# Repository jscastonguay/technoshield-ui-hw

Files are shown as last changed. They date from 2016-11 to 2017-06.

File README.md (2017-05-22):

# Technoshield User Interface HW

See the folling link for further details: [Technoshield Hackaday project](https://hackaday.io/project/21892-technoshield-user-interface)

## Release note

This is the description of the Technoshield HW revisions.

### Revision A

2017-05-03

The issue #1 has been fixed. This is the first revision that should be produced for students.

### Revision --
The first protoype revision.

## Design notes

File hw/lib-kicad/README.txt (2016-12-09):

Here are the sources of the labraries:

* KiCad-Libraries:
  https://github.com/imciner2/KiCad-Libraries
  Connectors.pretty rename Connectors_lib.pretty to be able to add it in 
  kicad. The Connectors.pretty already exist in kicad libraries.
  
* technoshield-lb:
  Libraries done during this project development.

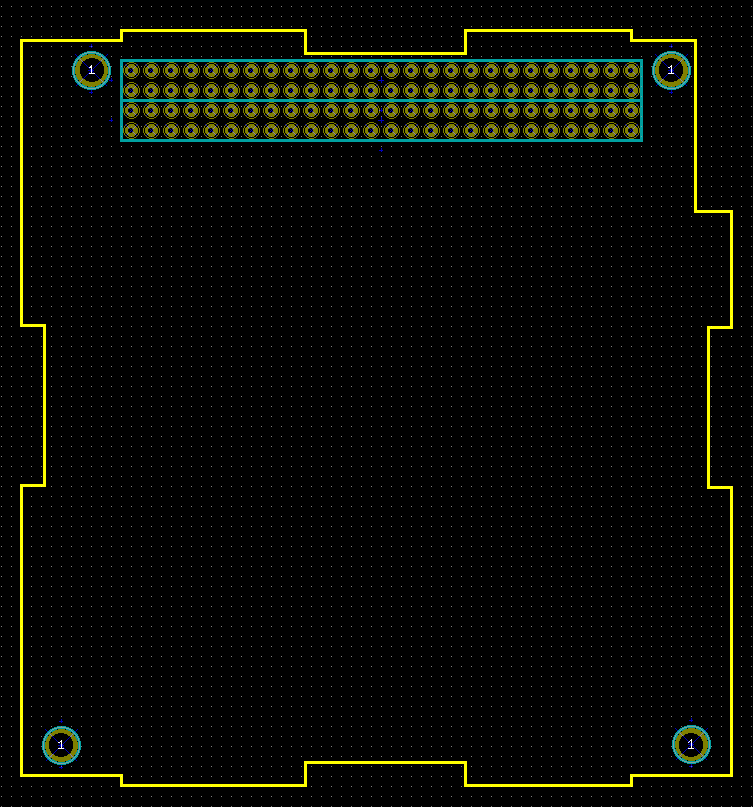
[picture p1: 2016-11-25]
hw/lib-kicad/KiCad-Libraries/Templates/CubeSatKit_StackBoard/meta/Board.png

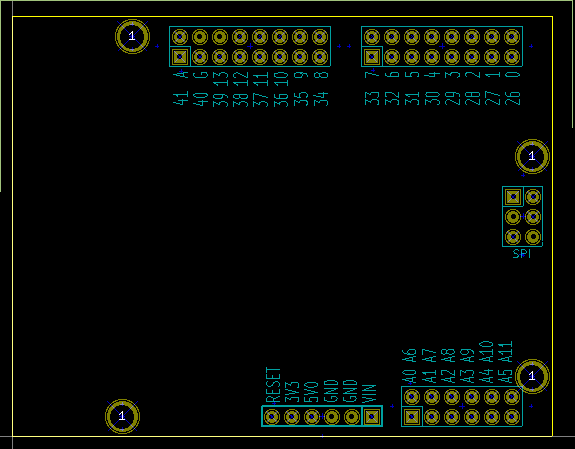
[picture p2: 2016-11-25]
hw/lib-kicad/KiCad-Libraries/Templates/Chipkit_Shield_uC/meta/board.png

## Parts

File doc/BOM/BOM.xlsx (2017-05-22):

Part list Technoshield User interface
Stock | QTE | Ref | Description | P/N | Fournisseur
 | 5 | R1, R2, R3, R4, R7 | RES 10K OHM 1/8W 5% CF AXIAL | CF18JT10K0CT-ND | DigiKey
 | 1 | R16 | RES 750 OHM 1/8W 5% CF AXIAL | CF18JT750RCT-ND | DigiKey
 | 3 | R11, R12, R13 | RES 1.6K OHM 1/8W 5% CF AXIAL | CF18JT1K60CT-ND | DigiKey
 | 2 | R14, R15 | RES 4.7K OHM 1/8W 5% CF AXIAL | CF18JT4K70CT-ND | DigiKey
 | 1 | RV1 | TRIMMER 10K OHM 0.2W PC PIN | 3319P-103-ND | DigiKey
 | 6 | C1, C2, C3, C4, C5, C6 | CAP CER 0.1UF 50V X7R RADIAL | 490-8815-ND | DigiKey
 | 1 | D1 | LED RED CLEAR 2PLCC SMD | 475-1180-1-ND | DigiKey
 | 1 | D2 | LED YELLOW CLEAR 2PLCC SMD | 475-2798-1-ND | DigiKey
 | 2 | D3, D4 | LED GREEN CLEAR 2PLCC SMD | 475-2752-1-ND | DigiKey
 | 1 | Q1 | TRANS NPN 40V 0.6A SMD SOT23-3 | MMBT2222A-FDICT-ND | DigiKey
 | 1 | U1 | DC/DC CONVERTER +/-15V 1W | 102-2721-ND | DigiKey
 | 2 | U2, U3 | IC I/O EXPANDER I2C 8B 18DIP | MCP23008-E/P-ND | DigiKey
 | 1 | U4 | IC BUFFER HEX NON-INV 16SOIC | 1727-6410-1-ND | DigiKey
 | 1 | J1 | CONN MICRO SD CARD HINGED TYPE | 101-00303-68-1-ND | DigiKey | Non-stock discontinued
 | 6 | JP1, JP2, JP3, JP4, JP5, JP6 | SIL VERTICAL PC TAIL PIN HEADER | 952-2262-ND | DigiKey
 | 6 | -- | *Jumper for JP1-JP2-JP3-JP4-JP5-JP6 SHUNT JUMPER .1" BLACK GOLD | 3M9580-ND | DigiKey
 | 1 | P1 | CONN HEADER FEMALE 3POS .1" GOLD | S7036-ND | DigiKey
 | 6 | SW1, SW2, SW3, SW4, SW5, SW6 | SWITCH TACTILE SPST-NO 0.05A 24V | 450-2055-1-ND | DigiKey
 | 1 | P3 | 6 pin 2,54p stack 11mm long tall leg female header | --- | AliExpress
 | 2 | P2, P5 | 8 pin 2.54p Stack 11mm long Tall Leg Female header | --- | AliExpress
 | 1 | P4 | 10 pin 2.54 Stack 11mm Long Tall Leg Female Header | --- | AliExpress

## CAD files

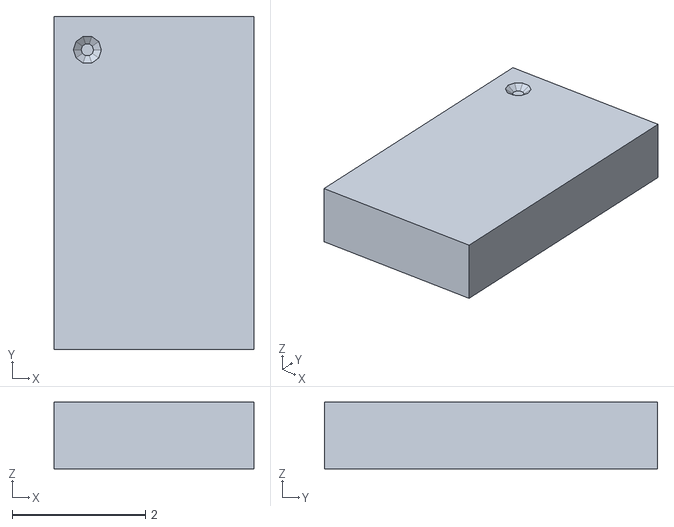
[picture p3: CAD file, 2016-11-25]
hw/lib-kicad/KiCad-Libraries/3D/SourceFiles/ADXL345/ADXL345-Wings.stl
3.00 x 5.00 x 1.00

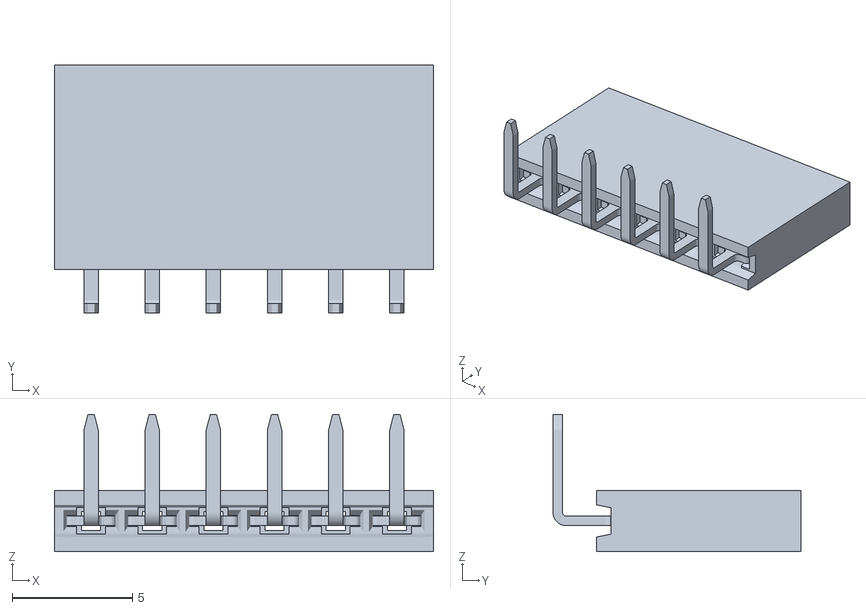
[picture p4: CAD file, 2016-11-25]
hw/lib-kicad/KiCad-Libraries/3D/SourceFiles/Connectors/CONN_1x6/CONN_1x6_Female.stl
15.7 x 10.3 x 5.69

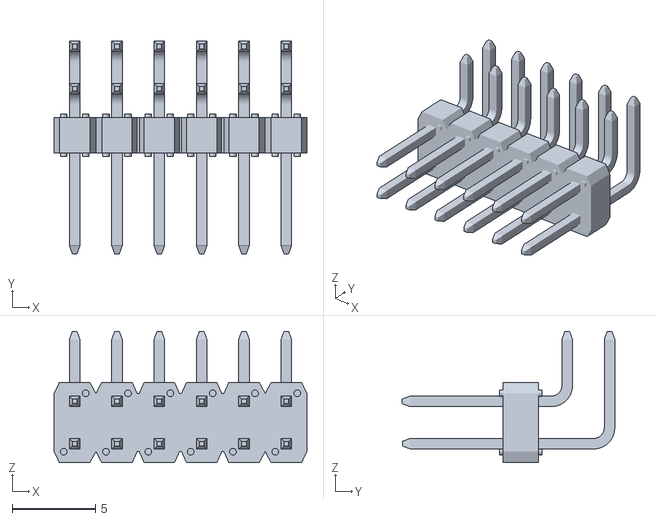
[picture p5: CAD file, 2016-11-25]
hw/lib-kicad/KiCad-Libraries/3D/SourceFiles/Connectors/CONN_2x6/CONN_2x6_Male.stl
15.2 x 12.8 x 7.89

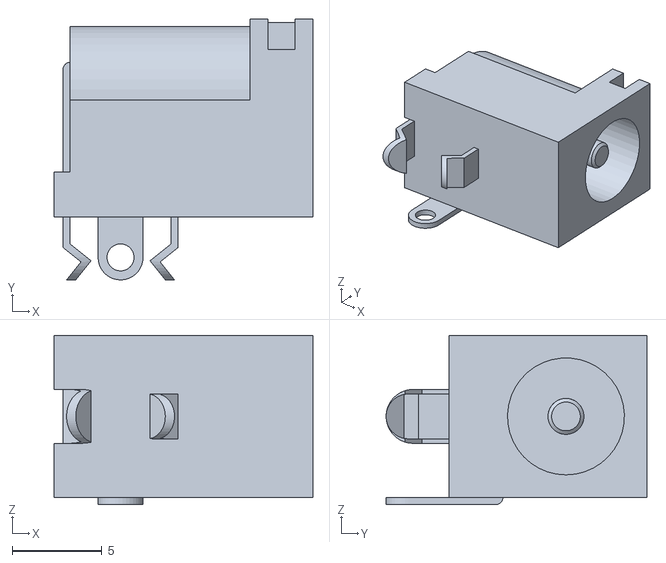
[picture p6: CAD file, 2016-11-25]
hw/lib-kicad/KiCad-Libraries/3D/SourceFiles/Connectors/DC_2.1mm_CUI-PJ-202A/DC_2.1mm_CUI-PJ-202A.stl
14.4 x 14.5 x 9.40

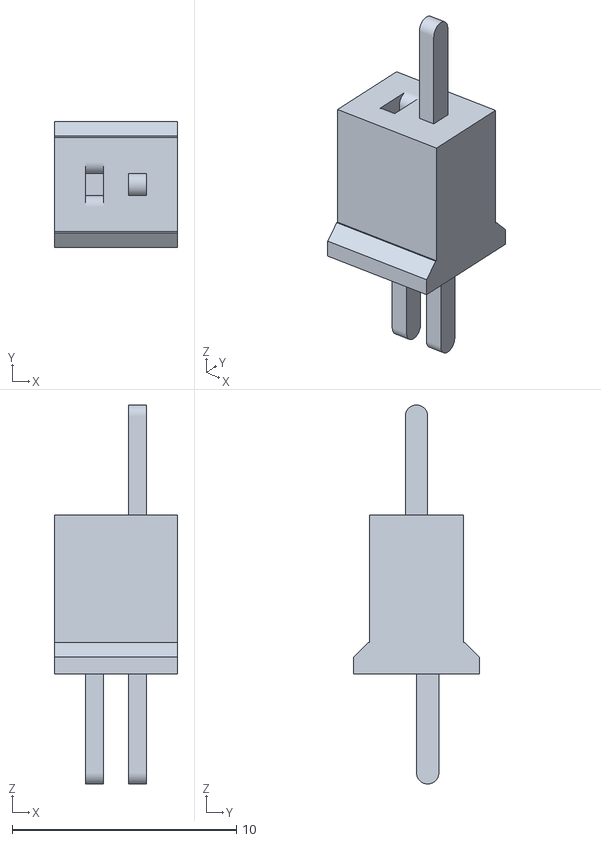
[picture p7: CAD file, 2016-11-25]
hw/lib-kicad/KiCad-Libraries/3D/SourceFiles/Connectors/Deans/DeansMicro-Wings.stl
5.50 x 5.60 x 16.9

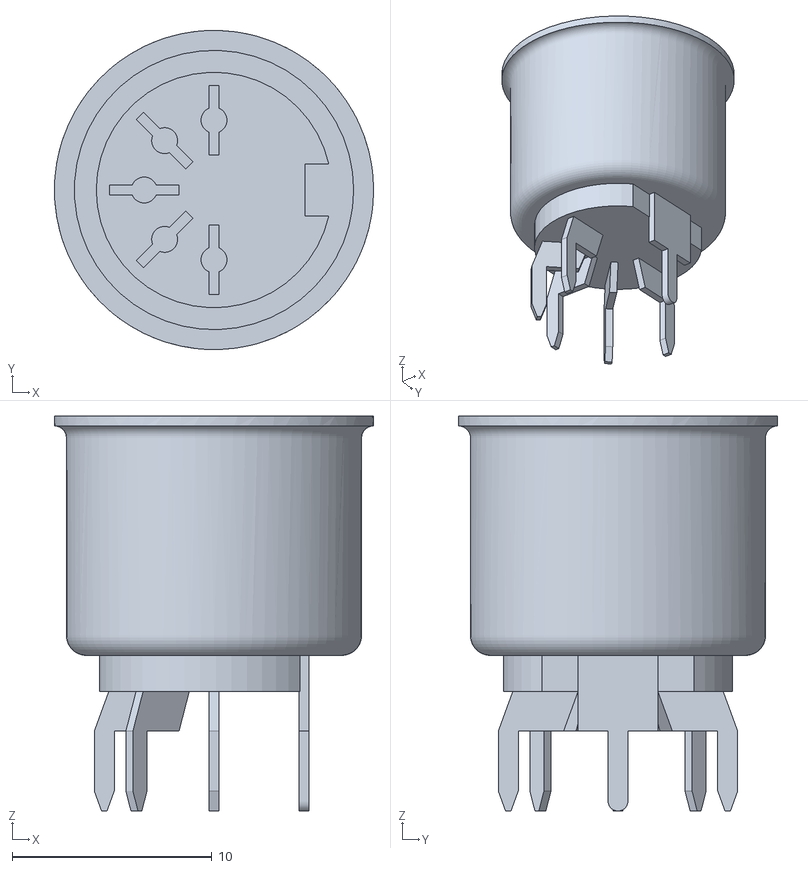
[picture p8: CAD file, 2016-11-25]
hw/lib-kicad/KiCad-Libraries/3D/SourceFiles/Connectors/DIN_CUI_SD-50BV/SD-50BV.stl
16.0 x 16.0 x 19.8

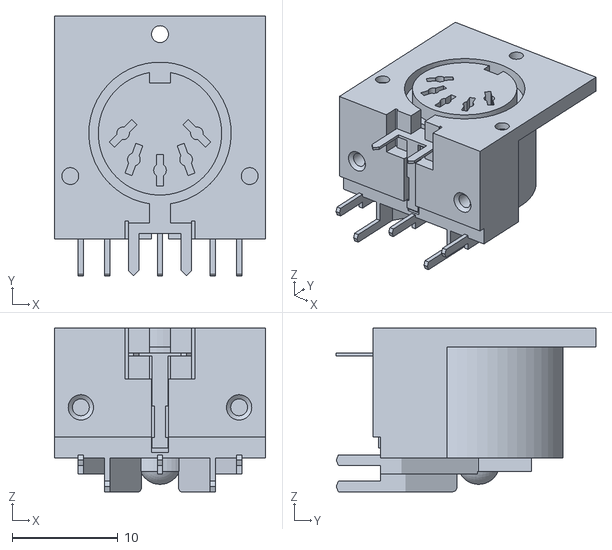
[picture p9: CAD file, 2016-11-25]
hw/lib-kicad/KiCad-Libraries/3D/SourceFiles/Connectors/DIN_CUI_SDS-50J/SDS-50J.stl
20.0 x 24.6 x 15.5

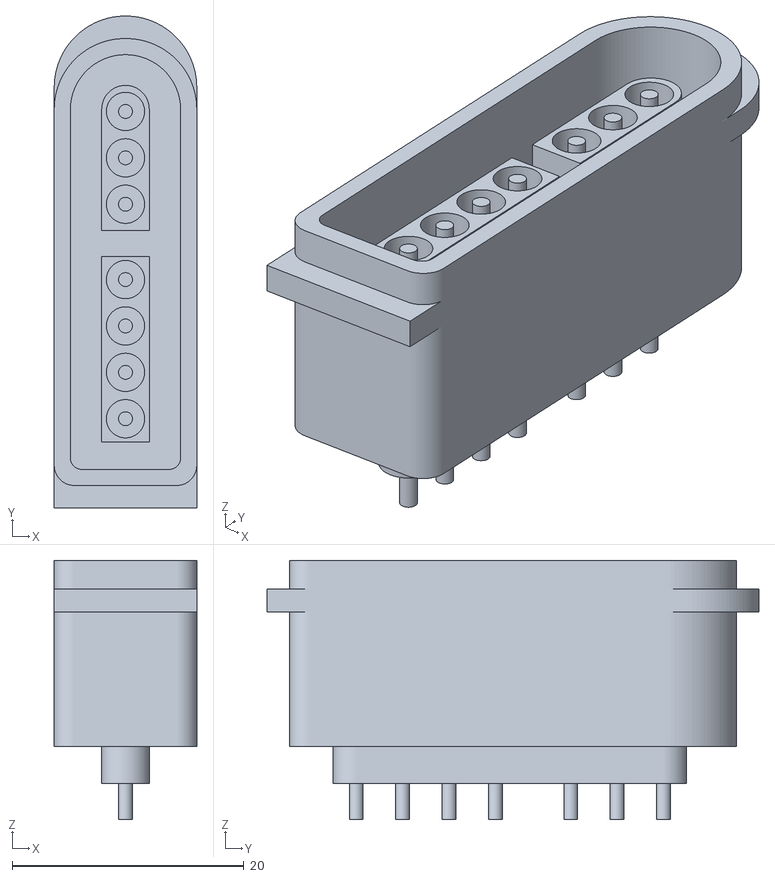
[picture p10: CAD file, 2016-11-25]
hw/lib-kicad/KiCad-Libraries/3D/SourceFiles/Connectors/Gaming_SNES/Gaming_SNES-wings.stl
12.3 x 42.4 x 22.3

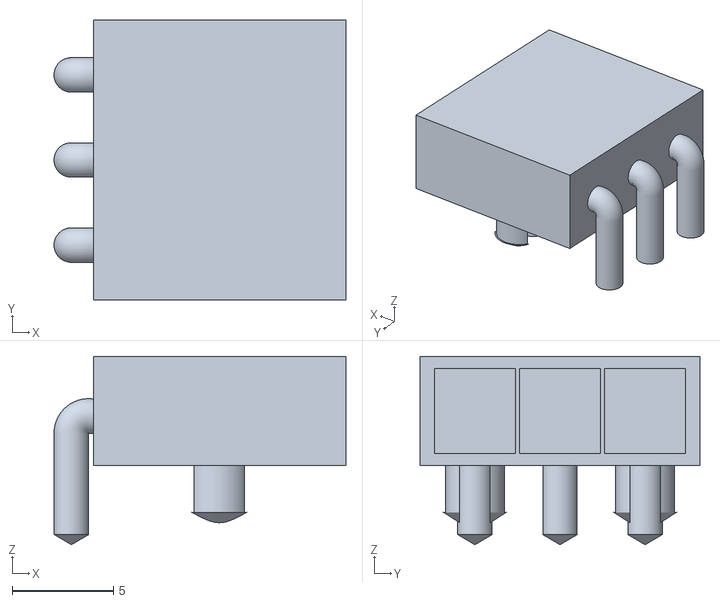
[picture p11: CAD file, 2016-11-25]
hw/lib-kicad/KiCad-Libraries/3D/SourceFiles/Connectors/MOLEX_MINI-FIT-JR_3_PTH_RT_PEG/MOLEX_MINI-FIT-JR_3_PTH_RT_PEG-scad.stl
14.4 x 13.8 x 9.30

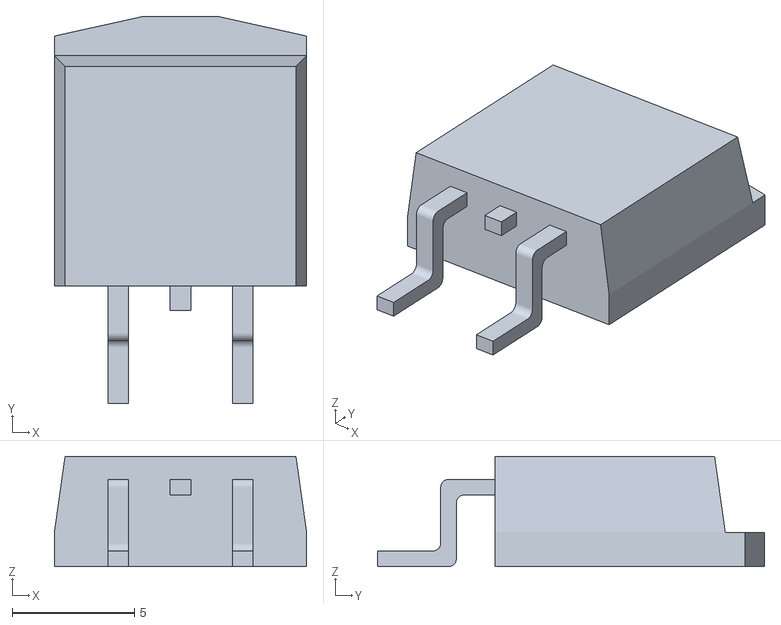
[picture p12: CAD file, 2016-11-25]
hw/lib-kicad/KiCad-Libraries/3D/SourceFiles/D2PACK/D2PACK-Wings.stl
10.3 x 15.8 x 4.50

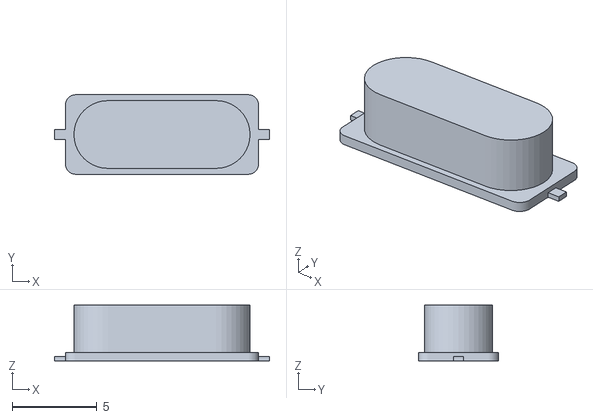
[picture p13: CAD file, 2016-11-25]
hw/lib-kicad/KiCad-Libraries/3D/SourceFiles/HC-49-SMT/HC-49-SMT-scad.stl
12.7 x 4.70 x 3.30

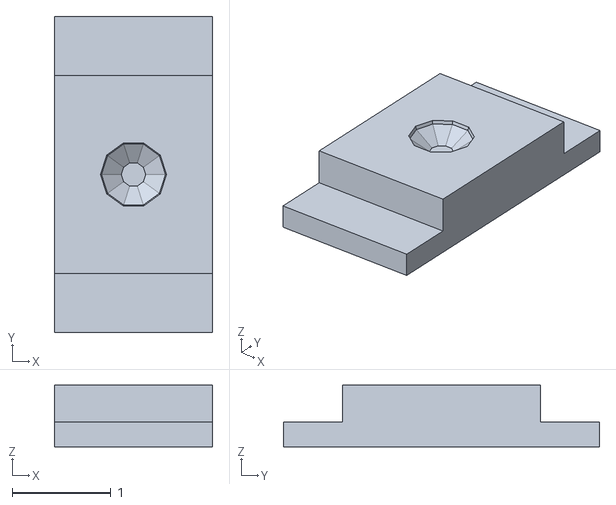
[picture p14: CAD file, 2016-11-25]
hw/lib-kicad/KiCad-Libraries/3D/SourceFiles/LEDs/LED-1206-Wings.stl
1.60 x 3.20 x 0.625

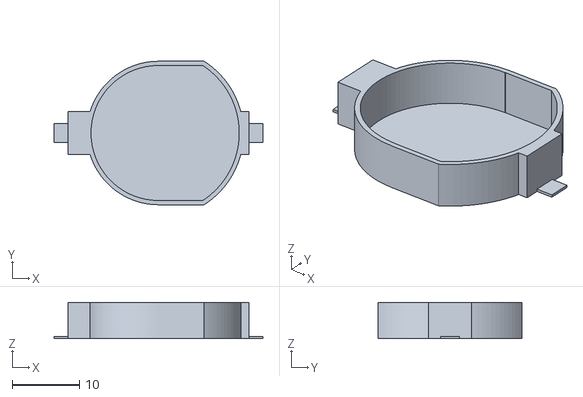
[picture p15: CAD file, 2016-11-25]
hw/lib-kicad/KiCad-Libraries/3D/SourceFiles/MPD_CR2032/MPD_CR2032-SCAD.stl
31.1 x 21.4 x 5.38

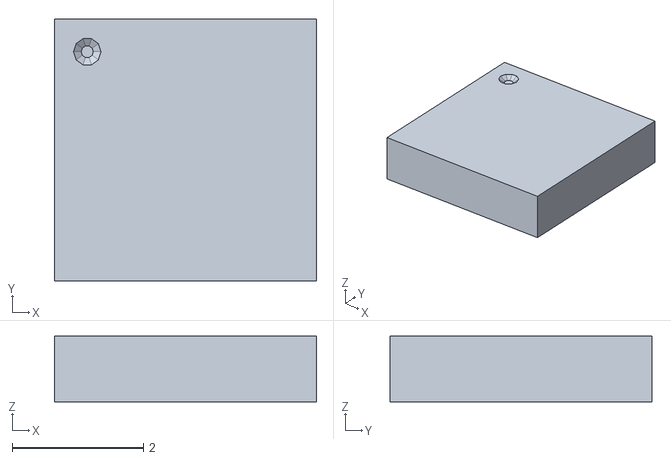
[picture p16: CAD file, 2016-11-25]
hw/lib-kicad/KiCad-Libraries/3D/SourceFiles/MPU9150/MPU9150-Wings.stl
4.00 x 4.00 x 1.00

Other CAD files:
hw/lib-kicad/KiCad-Libraries/3D/SourceFiles/SD_Objects/SD-Amp-microSlot-Wings.stl
hw/lib-kicad/KiCad-Libraries/3D/SourceFiles/SMD_Passives/SMD-0805-scad.stl
hw/lib-kicad/KiCad-Libraries/3D/SourceFiles/SOIC/SOIC_08_4.0mm_5.0mm_1.27mm-wings.stl
hw/lib-kicad/KiCad-Libraries/3D/SourceFiles/SolarCells/Spectrolab_TASC1-SCAD.stl
hw/lib-kicad/KiCad-Libraries/3D/SourceFiles/ADXL345/ADXL345.scad
hw/lib-kicad/KiCad-Libraries/3D/SourceFiles/D2PACK/D2PACK.scad
hw/lib-kicad/KiCad-Libraries/3D/SourceFiles/HC-49-SMT/HC-49-SMT.scad
hw/lib-kicad/KiCad-Libraries/3D/SourceFiles/LEDs/LED-1206.scad
hw/lib-kicad/KiCad-Libraries/3D/SourceFiles/ADXL345/ADXL345-SCAD.stl
hw/lib-kicad/KiCad-Libraries/3D/SourceFiles/Connectors/CONN_1x6/CONN_1x6_Male.stl
hw/lib-kicad/KiCad-Libraries/3D/SourceFiles/Connectors/CONN_2x6/CONN_2x6_Female.stl
hw/lib-kicad/KiCad-Libraries/3D/SourceFiles/Connectors/Deans/Deans-SCAD.stl
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

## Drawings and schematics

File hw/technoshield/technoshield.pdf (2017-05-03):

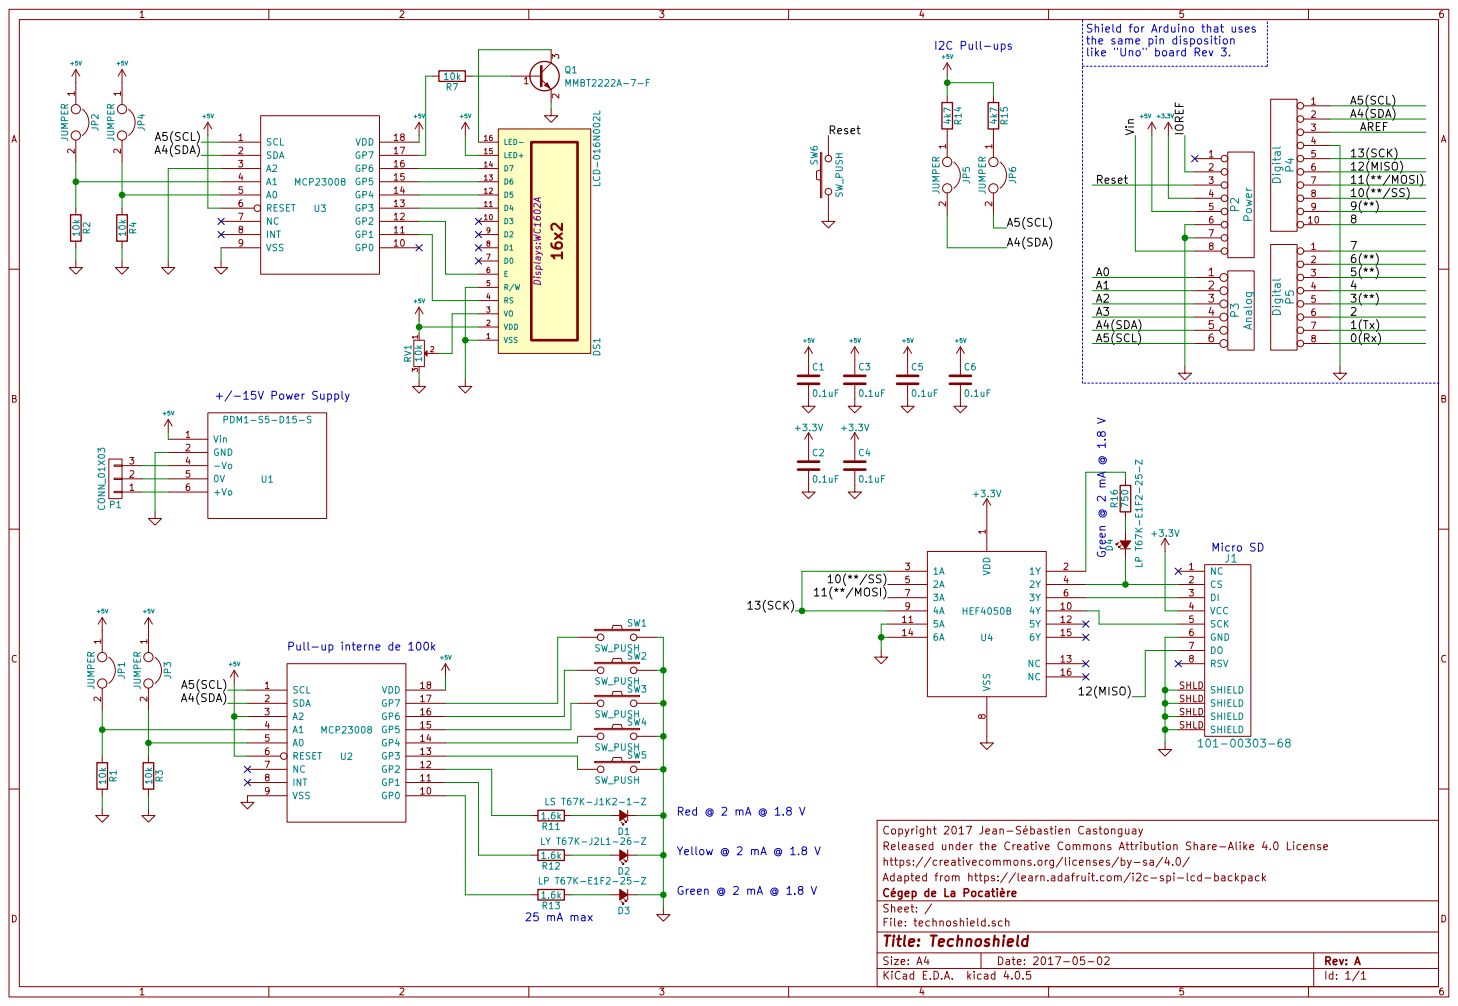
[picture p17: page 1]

Shield for Arduino that uses
the same pin disposition

like "Uno" board Rev 3. 16x2

https://creativecommons.org/licenses/by-sa/4.0/ Released under the Creative Commons Attribution Share-Alike 4.0 License Copyright 2017 Jean-Sébastien Castonguay

Adapted from https://learn.adafruit.com/i2c-spi-lcd-backpack
File: technoshield.sch Sheet: / Cégep de La Pocatière

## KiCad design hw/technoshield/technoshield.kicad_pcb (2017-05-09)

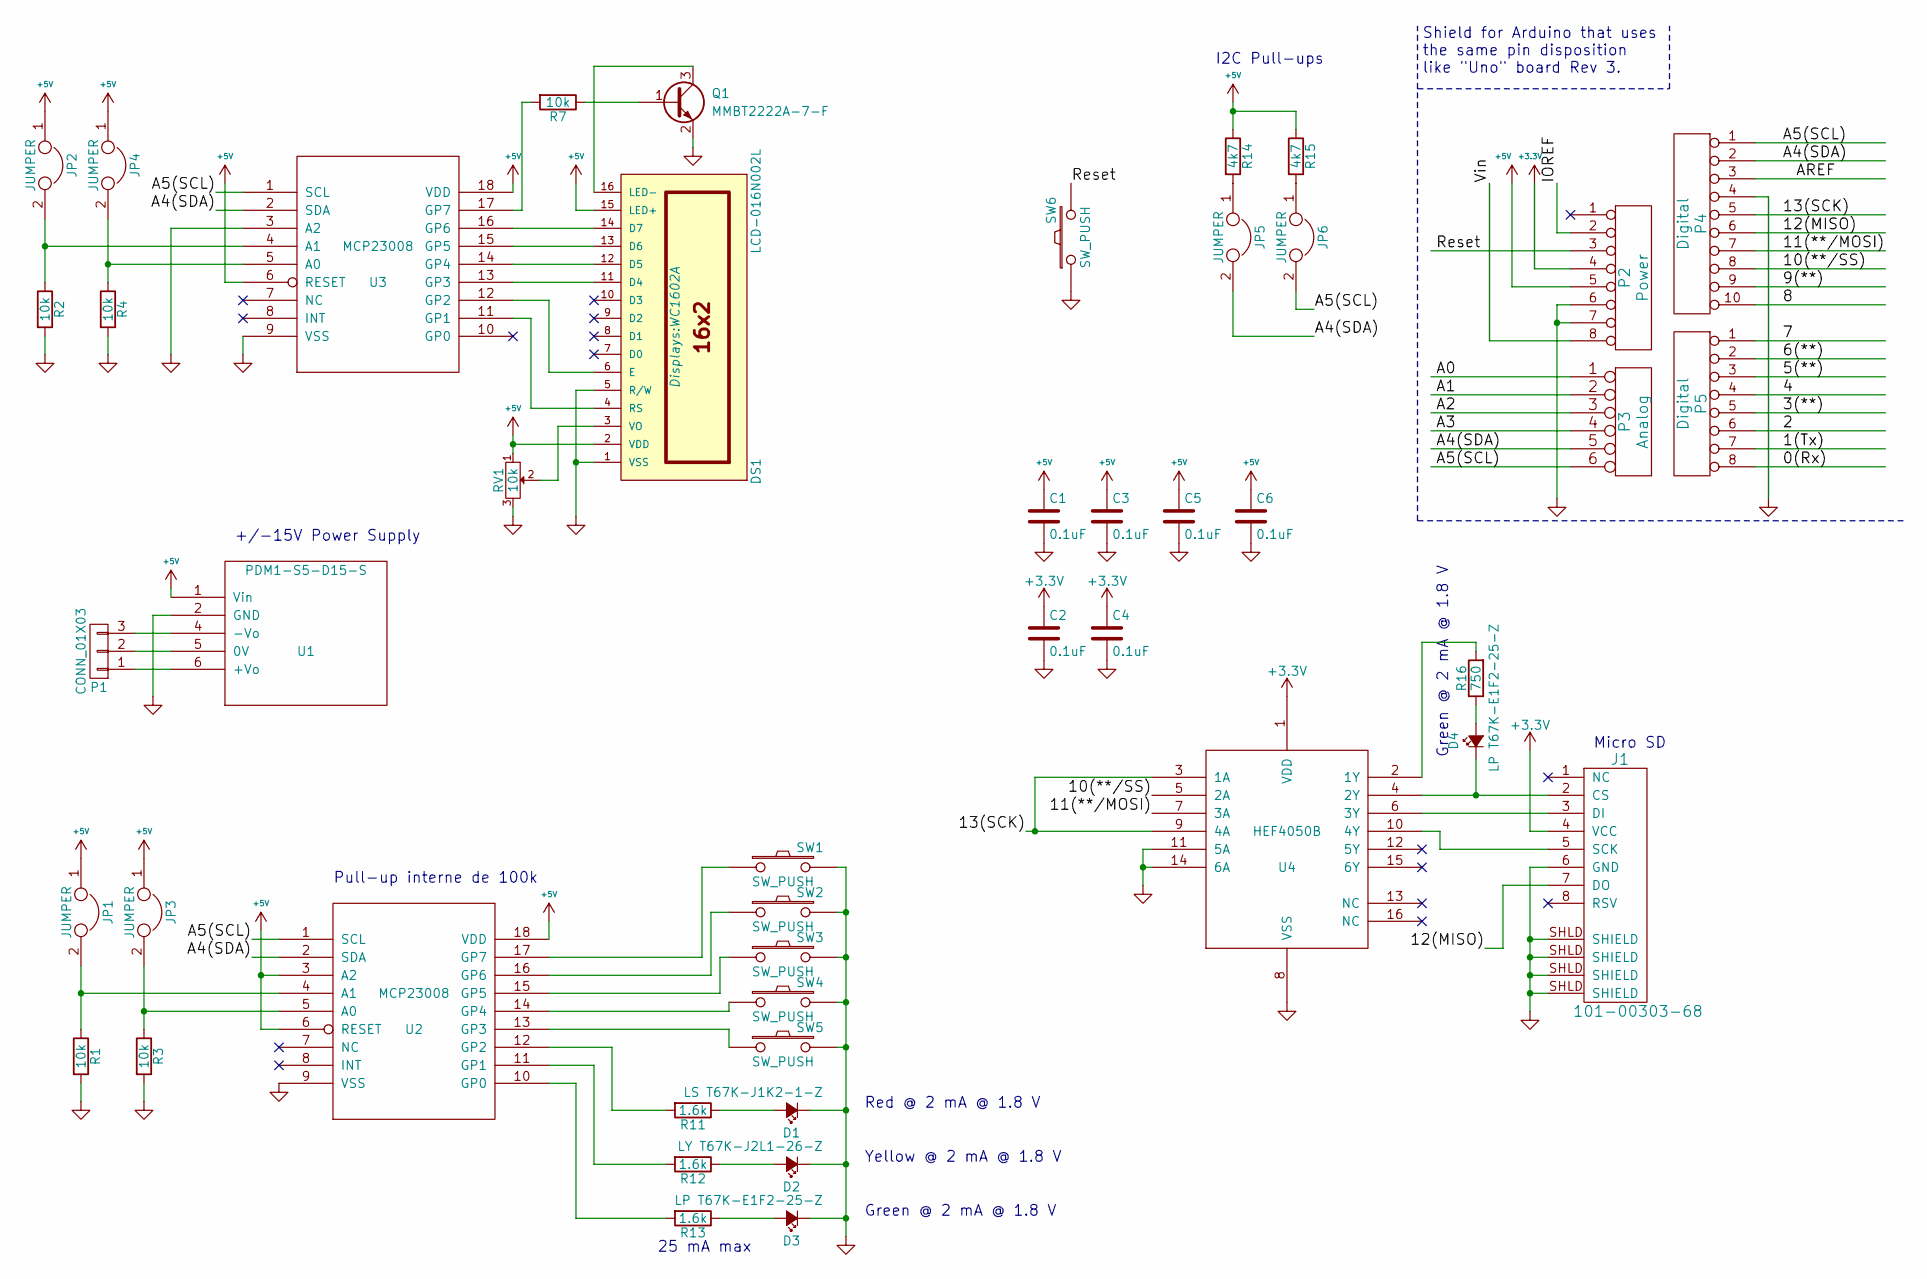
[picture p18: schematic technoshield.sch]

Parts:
C1, C2, C3, C4, C5, C6: 0.1uF; C_Disc_D3.0mm_W1.6mm_P2.50mm
D1: LS T67K-J1K2-1-Z; T67K
D2: LY T67K-J2L1-26-Z; T67K
D3, D4: LP T67K-E1F2-25-Z; T67K
DS1: LCD-016N002L; WC1602A
J1: 101-00303-68; MICRO_SD_HINGE_AMP
JP1, JP2, JP3, JP4, JP5, JP6: JUMPER; Pin_Header_Straight_1x02_Pitch2.54mm
P1: CONN_01X03; Pin_Header_Straight_1x03_Pitch2.54mm
P2: Power; Socket_Strip_Arduino_1x08
P3: Analog; Socket_Strip_Arduino_1x06
P4: Digital; Socket_Strip_Arduino_1x10
P5: Digital; Socket_Strip_Arduino_1x08
Q1: MMBT2222A-7-F; SOT-23
R1, R2, R3, R4, R7: 10k; R_Axial_DIN0204_L3.6mm_D1.6mm_P7.62mm_Horizontal
R11, R12, R13: 1.6k; R_Axial_DIN0204_L3.6mm_D1.6mm_P7.62mm_Horizontal
R14, R15: 4k7; R_Axial_DIN0204_L3.6mm_D1.6mm_P7.62mm_Horizontal
R16: 750; R_Axial_DIN0204_L3.6mm_D1.6mm_P7.62mm_Horizontal
RV1: 10k; POTENTIOMETRE_BOURNS_3319P
SW1, SW2, SW3, SW4, SW5, SW6: SW_PUSH; smt_btn
U1: PDM1-S5-D15-S; PDM1-S
U2, U3: MCP23008; DIP-18_W7.62mm_LongPads
U4: HEF4050B; SO16-3_9mm

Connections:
+3V3: C2.1, C4.1, J1.4 (VCC), P2.4, U4.1 (VDD)
+5V: C1.1, C3.1, C5.1, C6.1, DS1.2 (VDD), DS1.15 (LED+), JP1.1, JP2.1, JP3.1, JP4.1, P2.5, R14.1, R15.1, RV1.1, U1.1 (Vin), U2.3 (A2), U2.6 (RESET), U2.18 (VDD), U3.6 (RESET), U3.18 (VDD)
/0(Rx): P5.8
/1(Tx): P5.7
/2: P5.6
/3(**): P5.5
/4: P5.4
/5(**): P5.3
/6(**): P5.2
/7: P5.1
/8: P4.10
/9(**): P4.9
/10(**/SS): P4.8, U4.5 (2A)
/11(**/MOSI): P4.7, U4.7 (3A)
/12(MISO): J1.7 (DO), P4.6
/13(SCK): P4.5, U4.3 (1A), U4.9 (4A)
/A0: P3.1
/A1: P3.2
/A2: P3.3
/A3: P3.4
/A4(SDA): JP5.2, P3.5, P4.2, U2.2 (SDA), U3.2 (SDA)
/A5(SCL): JP6.2, P3.6, P4.1, U2.1 (SCL), U3.1 (SCL)
/AREF: P4.3
/IOREF: P2.2
/Reset: P2.3, SW6.2
/Vin: P2.8
GND: C1.2, C2.2, C3.2, C4.2, C5.2, C6.2, D1.1 (K), D2.1 (K), D3.1 (K), DS1.1 (VSS), DS1.5 (R/W), J1.6 (GND), J1.SHLD (SHIELD), P2.6, P2.7, P4.4, Q1.2 (E), R1.2, R2.2, R3.2, R4.2, RV1.3, SW1.2, SW2.2, SW3.2, SW4.2, SW5.2, SW6.1, U1.2 (GND), U2.9 (VSS), U3.3 (A2), U3.9 (VSS), U4.8 (VSS), U4.11 (5A), U4.14 (6A)
unnamed: D1.2 (A), R11.1
unnamed: D2.2 (A), R12.1
unnamed: D3.2 (A), R13.1
unnamed: D4.1 (K), J1.2 (CS), U4.4 (2Y)
unnamed: D4.2 (A), R16.1
unnamed: DS1.3 (VO), RV1.2
unnamed: DS1.4 (RS), U3.11 (GP1)
unnamed: DS1.6 (E), U3.12 (GP2)
unnamed: DS1.11 (D4), U3.13 (GP3)
unnamed: DS1.12 (D5), U3.14 (GP4)
unnamed: DS1.13 (D6), U3.15 (GP5)
unnamed: DS1.14 (D7), U3.16 (GP6)
unnamed: DS1.16 (LED-), Q1.3 (C)
unnamed: J1.3 (DI), U4.6 (3Y)
unnamed: J1.5 (SCK), U4.10 (4Y)
unnamed: JP1.2, R1.1, U2.4 (A1)
unnamed: JP2.2, R2.1, U3.4 (A1)
unnamed: JP3.2, R3.1, U2.5 (A0)
unnamed: JP4.2, R4.1, U3.5 (A0)
unnamed: JP5.1, R14.2
unnamed: JP6.1, R15.2
unnamed: P1.1, U1.6 (+Vo)
unnamed: P1.2, U1.5 (0V)
unnamed: P1.3, U1.4 (-Vo)
unnamed: Q1.1 (B), R7.1
unnamed: R7.2, U3.17 (GP7)
unnamed: R11.2, U2.12 (GP2)
unnamed: R12.2, U2.11 (GP1)
unnamed: R13.2, U2.10 (GP0)
unnamed: R16.2, U4.2 (1Y)
unnamed: SW1.1, U2.17 (GP7)
unnamed: SW2.1, U2.16 (GP6)
unnamed: SW3.1, U2.15 (GP5)
unnamed: SW4.1, U2.14 (GP4)
unnamed: SW5.1, U2.13 (GP3)

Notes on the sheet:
Shield for Arduino that uses the same pin disposition like "Uno" board Rev 3.
I2C Pull-ups
Pull-up interne de 100k
25 mA max
+/-15V Power Supply
Red @ 2 mA @ 1.8 V
Yellow @ 2 mA @ 1.8 V
Green @ 2 mA @ 1.8 V
Micro SD

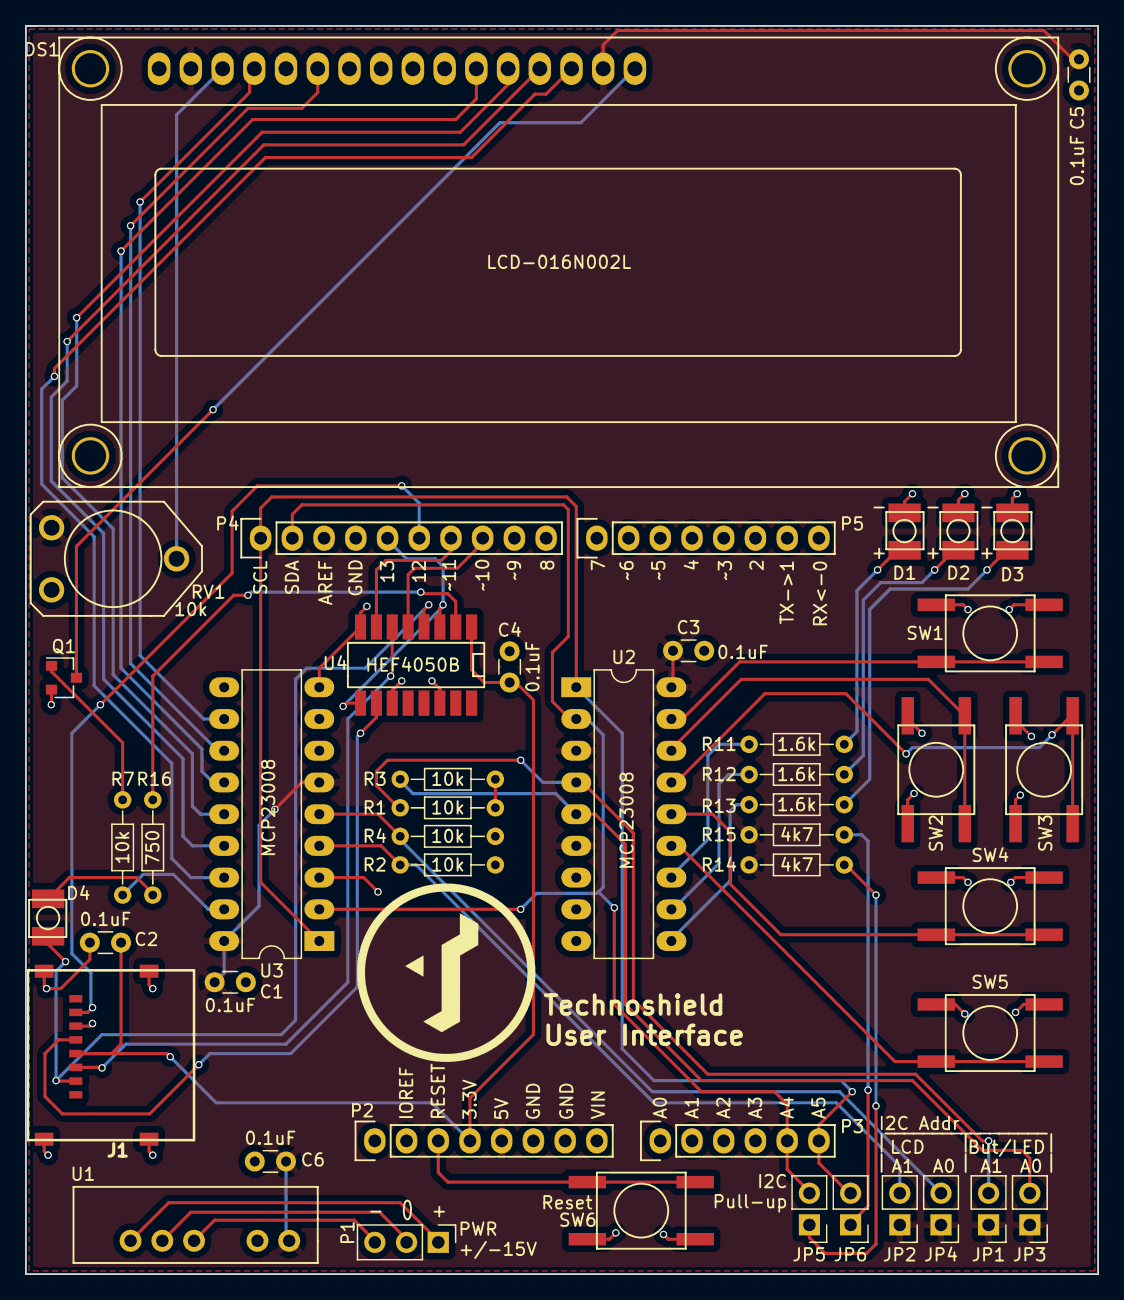
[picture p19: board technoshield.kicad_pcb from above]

Board: 2 copper layers, 85.9 x 99.9 mm, 46 parts (0 on the bottom side), 45 nets.

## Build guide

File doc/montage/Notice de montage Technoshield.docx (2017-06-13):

Notice de montage du Technoshield Rev.A

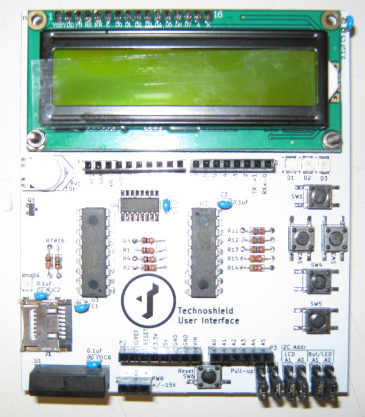
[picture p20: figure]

1. Ordre de montage : En règle général on commence toujours par souder les composantes SURFACE MOUNT. Dans ce cas-ci, parmis les pièces SMT , il est préférable de commencer par souder les diodes avant les boutons pressoir.
2. Orientation des pièces : Certaines pièces ont des orientations particulières qui sont habituellement indiqué par la sérigraphie sur la carte. Il faut avoir en tête les composantes qui nécéssitent une orientation parce qu’en prototypage il arrive que les sérigraphies comportent des erreurs et ne l’indique pas. Il faut alors aller vérifier soit même avec le schéma électrique et les spécifications des composantes. Sur le technoshield , 2 composantes ont des orientations particulières ; les diodes D1-D2-D3-D4 et le chip U4 . L’orientation des diodes D1-D2 et D3 sont indiqué mais pas la D4. Il faut donc vérifier sur le schéma pour son orientation.

Figure 1- Orientation des diodes

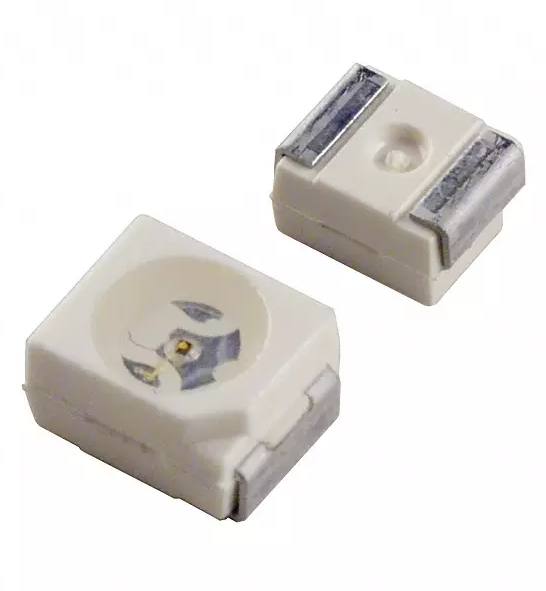
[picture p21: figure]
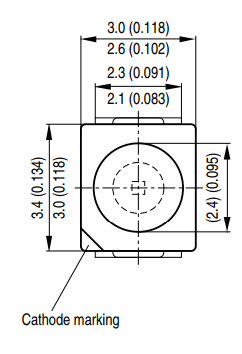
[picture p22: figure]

Figure 2 - Orientation de U4

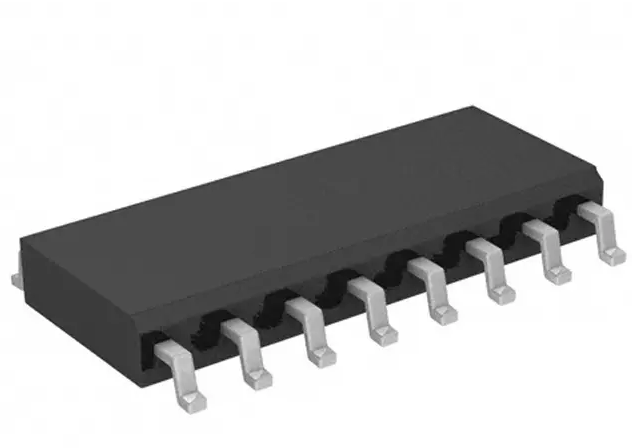
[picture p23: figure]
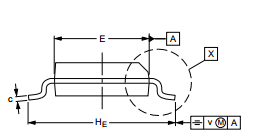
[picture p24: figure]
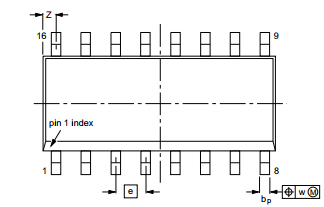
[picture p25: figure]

3. Technique de soudage SMT : Mettre de l’étain sur un des pads , prendre la composante avec des pinces et l’approcher du pad tout en le chauffant. S’assurer que la pièce est bien placée avant de souder les pattes restantes.
4. Technique de montage THROUGH HOLE :

Pour les résistances et condensateurs , contraindre les composantes à rester en place avant la soudure en pliant les pattes .

Pour les connecteurs , tenir une des pins avant de tourner la carte et souder une pin ( non tenu par les doigts) avec un fer à souder sur lequel se trouve déjà de l’étain. Retourner pour vérifier le placement , lorsque le connecteur est bien placé , souder le reste des pins.

Les connecteurs P2, P3, P4, P5 seront difficile à souder droit. Il est conseillé de placer un arduino sur la carte pour assurer un placement parfait lors du soudage.

Les connecteurs JP1-JP2-JP3-JP4-JP5-JP6 ont des jumper . Pour fonctionner au démarrage , les jumper ne doivent pas être présents. Pour commencer, placer les jumper sur 1 pin seulement.

5. Nettoyage : Il est important de toujours nettoyer une carte après son montage. L’effet d’un manque de nettoyage ne sera pas remarqué immédiatement mais à plus long terme. Certains type de résine contenu dans l’étain ou le flux peuvent aller jusqu’à gruger la carte lorsqu’aucun nettoyage n’a lieu. Certains étains ont un core en flux ‘’no clean’’ qui ne nécéssite pas de nettoyage, d’autres en nécéssite. Utiliser un produit Flux remover SAFE FOR PLASTIC et suivre les instructions sur la bouteille.
6. Décharge électrostatique : Le port du bracelet antistatique est conseillé lors de toutes manipulations d’une carte électronique. Si aucune bracelet n’est disponible , manipuler la carte par les côté. Ne jamais se prêter des cartes de main à main. Poser d’abord la carte sur une table avant de transférer la carte à quelqu’un d’autres. Un choc sur un chip non protégé peut causer des problèmes intermittents qui sont dures à diagnostiquer. Il arrive que le choc n’est pas ressenti même s’il est bien arrivé !

Tableau 1 - Liste de pièces du Technoshield

QTE | Ref | Description | Part number | Fournisseur
1 | PCB | PCB | --- | Elecrow
5 | R1, R2, R3, R4, R7 | RES 10K OHM 1/8W 5% CF AXIAL | CF18JT10K0CT-ND | DigiKey
1 | R16 | RES 750 OHM 1/8W 5% CF AXIAL | CF18JT750RCT-ND | DigiKey
3 | R11, R12, R13 | RES 1.6K OHM 1/8W 5% CF AXIAL | CF18JT1K60CT-ND | DigiKey
2 | R14, R15 | RES 4.7K OHM 1/8W 5% CF AXIAL | CF18JT4K70CT-ND | DigiKey
1 | RV1 | TRIMMER 10K OHM 0.2W PC PIN | 3319P-103-ND | DigiKey
6 | C1, C2, C3, C4, C5, C6 | CAP CER 0.1UF 50V X7R RADIAL | 490-8815-ND | DigiKey
1 | D1 | LED RED CLEAR 2PLCC SMD | 475-1180-1-ND | DigiKey
1 | D2 | LED YELLOW CLEAR 2PLCC SMD | 475-2798-1-ND | DigiKey
2 | D3, D4 | LED GREEN CLEAR 2PLCC SMD | 475-2752-1-ND | DigiKey
1 | DS1 | HD44780 Character LCD Display Module LCM blue blacklight | Lien (http://www.ebay.ca/itm/10PCS1602-New-1602-16x2-HD44780-Character-LCD-Display-Module-LCM-blue-blacklight-/351492865804) ebay | Ebay
1 | ---DS1 | CONN HEADER 16POS .100 STR TIN | 609-3267-ND | DigiKey
1 | Q1 | TRANS NPN 40V 0.6A SMD SOT23-3 | MMBT2222A-FDICT-ND | DigiKey
1 | U1 | DC/DC CONVERTER +/-15V 1W | 102-2721-ND | DigiKey
2 | U2, U3 | IC I/O EXPANDER I2C 8B 18DIP | MCP23008-E/P-ND | DigiKey
1 | U4 | IC BUFFER HEX NON-INV 16SOIC | 1727-6410-1-ND | DigiKey
1 | J1 | CONN MICRO SD CARD HINGED TYPE | 101-00303-68-1-ND | DigiKey
6 | JP1, JP2, JP3, JP4, JP5, JP6 | SIL VERTICAL PC TAIL PIN HEADER, 2 pos | 952-2262-ND | DigiKey
6 | -- | *Jumper for JP1-JP2-JP3-JP4-JP5-JP6 SHUNT JUMPER .1" BLACK GOLD | 3M9580-ND | DigiKey
1 | P1 | CONN HEADER FEMALE 3POS .1" GOLD | S7036-ND | DigiKey
6 | SW1, SW2, SW3, SW4, SW5, SW6 | SWITCH TACTILE SPST-NO 0.05A 24V | 450-2055-1-ND | DigiKey
1 | P3 | 6 pin 2,54p stack 11mm long tall leg female header | --- | AliExpress
2 | P2, P5 | 8 pin 2.54p Stack 11mm long Tall Leg Female header | --- | AliExpress
1 | P4 | 10 pin 2.54 Stack 11mm Long Tall Leg Female Header | --- | AliExpress
2 | ‘--- | Stainless Steel Phillips Decorative Rounded Head Screws 2-56 Thread Size | 91773A079 | McMaster
2 | ‘--- | Low-Strength Steel Hex Nut Zinc-Plated, 2-56 Thread Size | 90480A003 | McMaster
2 | ‘--- | Spacer nylon 3mm ID 5mm OD épaisseur 2,5mm | --- | ---

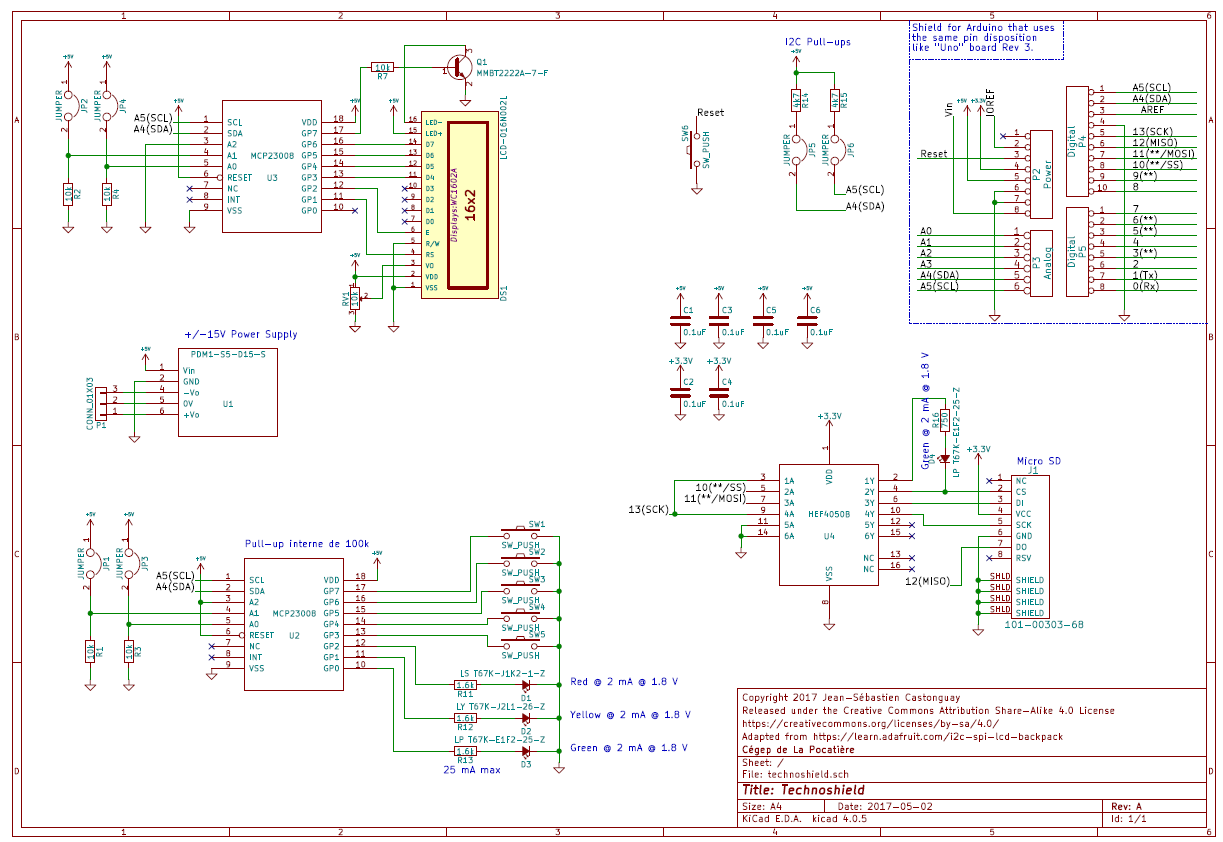
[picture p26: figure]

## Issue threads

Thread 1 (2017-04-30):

Problems found in prototype rev--

jscastonguay, 2017-04-30:
1. Vérifier certaines sérigraphies sur la face du haut
2. Déconnecter SCL/SDA des pins A4/A5
3. Vérifier l'espacement entre les trois LED: il ne semble pas égal.
4. Fautes sur la sérigraphie
5. U4 - indication de la pin 1
6. Sérigraphie D1 à D4
7. Ajouter des condensateurs à la sortie de l'alimentation +/- 15V (update: selon la datasheet, 0.47 uF mais aec la note suivante: It’s not recommended to connect any external capacitors in applications with less than 0.5 watt output.)
8. Le connecteur USB fait contacte avec des soudures de composants
9. Utiliser un convertisseur DC-DC surface mount au lieu de through hold (Ces items sont 33% moins cher. Econoline DC/DC Converter de Recom Pièce: RSD_0515/H) (update: la pièce semble obsolète pis elle coûte 10$ aujourd'hui)

jscastonguay, 2017-05-03:
1. Vérifier certaines sérigraphies sur la face du haut
Fait.

2. Déconnecter SCL/SDA des pins A4/A5
Après vérification, la plupart des shields s'attendent à accèder au I2C via A4/A5.

3. Vérifier l'espacement entre les trois LED: il ne semble pas égal.
Soudure. La dimension est OK.

4. Fautes sur la sérigraphie
Fait.

5. U4 - indication de la pin 1
Déjà là.

6. Sérigraphie D1 à D4
Fait.

7. Ajouter des condensateurs à la sortie de l'alimentation +/- 15V

On change rien. À l'oscilloscope, c'est OK. Selon la datasheet, 0.47 uF mais avec la note suivante: It’s not recommended to connect any external capacitors in applications with less than 0.5 watt output.

8. Le connecteur USB fait contacte avec des soudures de composants
Composants déplacés

9. Utiliser un convertisseur DC-DC surface mount au lieu de through hold(Ces items sont 33% moins cher. Econoline DC/DC Converter de Recom Pièce: RSD_0515/H)
La pièce semble obsolète pis elle coûte 10$ aujourd'hui

jscastonguay, 2017-05-03:
Item réglé dans la révision A.

Closed 2017-05-03.

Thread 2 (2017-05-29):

D4 polarity missing

jscastonguay, 2017-05-29:
Add D4 LED polarity on PCB.

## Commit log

2016-11-25 Durant le développement.
    [ADXL345-SCAD.stl, ADXL345-Wings.stl, ADXL345.scad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]
2016-12-09 During developpment.
    [technoshield.sch]
2017-01-22 During dev.
    [technoshield.sch]
2017-02-03 During dev PCB.
    [technoshield.kicad_pcb, technoshield.sch]
2017-02-04 Dev of Rev -- almost finish.
    [technoshield.kicad_pcb, technoshield.sch]
2017-02-09 Gerber done.
    [technoshield.kicad_pcb, technoshield.sch]
2017-05-01 Issue #1: Problems found in prototype rev-- Problem with USB and component contact fixed.
    [technoshield.kicad_pcb]
2017-05-02 Add logo.
    [technoshield.kicad_pcb]
2017-05-03 Issue #1 fixed.
    [technoshield-B.Cu.gbr, technoshield-B.Mask.gbr, technoshield-B.SilkS.gbr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]
2017-05-22 BOM added.
    [BOM.xlsx]
2017-06-13 "Notice de montage Technoshield.docx" added.
